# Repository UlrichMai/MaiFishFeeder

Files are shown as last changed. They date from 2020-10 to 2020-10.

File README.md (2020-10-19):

# Smart Fish Feeder

This fish feeder is for a small cylindric aquarium 30x30cm.
The fish need only small amount of food, and most other solution are just to big of unprecise.
This feeder has 14 chambers for food portions.
A 180 degree servo rotates the hole to drop the food.
Once the software is ready, there will be 2 actions that can be controlled
1. feed 1 portion: The disc will rotate to drop the next portion.
2. refill: the disc will rotate to the beginning an you can refill the disc holes.

## Part List
- SG90 servo
- ESP8266 D1 mini
- USB panel jack
- 3D printed parts [top](doc/fishfeeder_top.stl), [body](doc/fishfeeder_body.stl), [bottom](doc/fishfeeder_bottom.stl)

## todo
- improve 3D parts
- decide wether to build my own firmware or to use Tasmota.
  - Tasmota PWM feature is able to control the servo. pwm 38..140 results in the neccessary servo movement
  - the servo its self needs pulses ranging from 750..2600 microseconds for the 180 range
- requirements
  - the current servo position must be persisted
  - a reset or power cycle must not move the servo, so not unwanted food is dropped.

## Whishlist
- add a ESP32 cam as a webcam for the aquarium
- add a water temperatur sensor

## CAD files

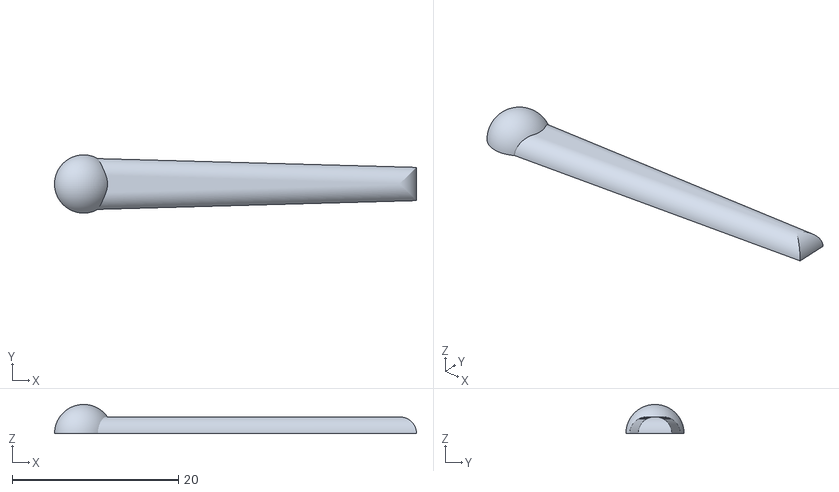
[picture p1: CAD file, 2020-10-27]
doc/Portionierer.stl
43.5 x 7.00 x 3.50

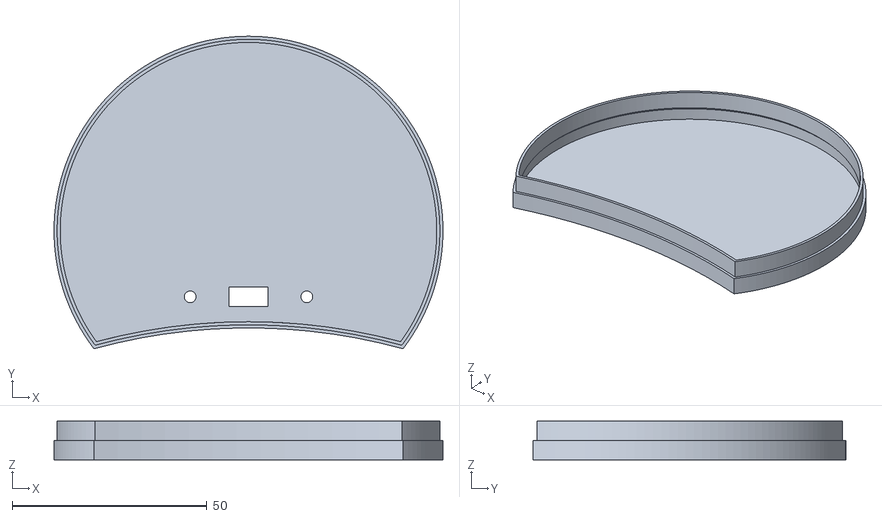
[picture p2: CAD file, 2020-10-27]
doc/fishfeeder_bottom.stl
100.0 x 80.4 x 10.0

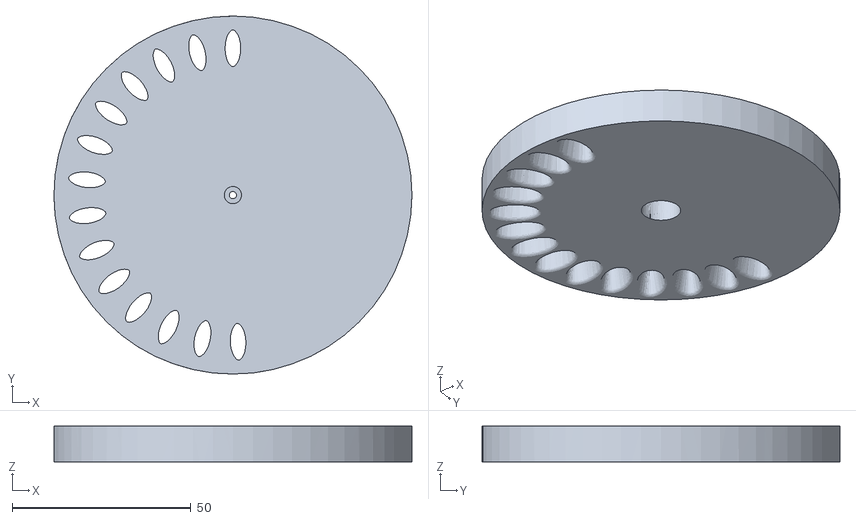
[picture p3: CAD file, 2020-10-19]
doc/fishfeeder_top.stl
100.0 x 100.0 x 9.96

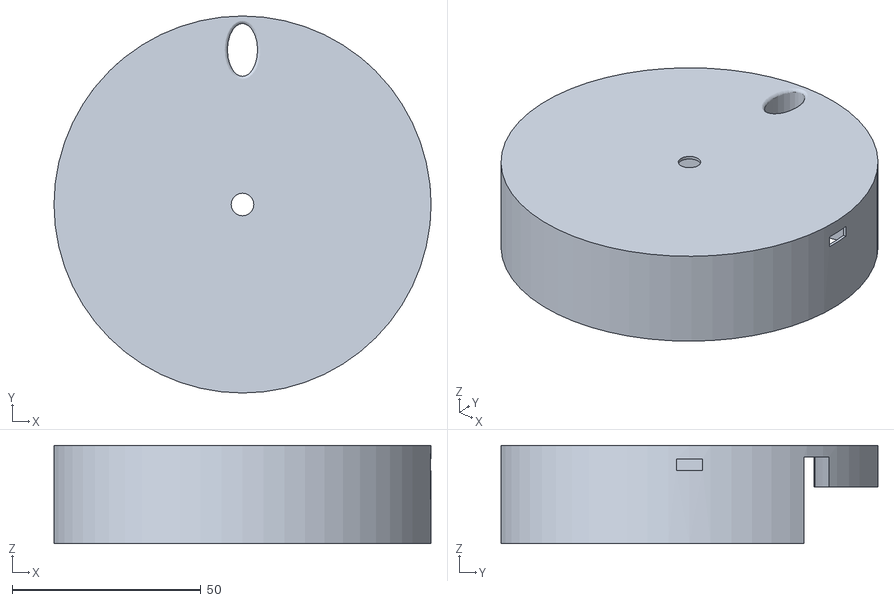
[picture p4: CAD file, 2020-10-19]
doc/fishfeeder_body.stl
100.0 x 100.0 x 26.0

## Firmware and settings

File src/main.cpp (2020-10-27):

#include <Arduino.h>
#include <ESP8266WiFi.h>
#include <ESP8266WebServer.h>
#include <ArduinoOTA.h>
#include <Servo.h>

#include "Private.h"

// Webserver on port 80
ESP8266WebServer server(80);

#define SERVO_PIN 4

Servo myservo;
// cable colors SG90 servo:
// brown=GND, red=5V, orange=pulse 

const int FeederPos[] = {2702,2559,2416,2273,2130,1987,1844,1701,1558,1415,1272,1129,986,843,700,0};
int ServoPos = 0; // to be persisted
uint32_t LastServoMove = 1;

void refill() {
  myservo.attach(SERVO_PIN);
  ServoPos = 0;
  int ms = FeederPos[ServoPos];
  myservo.writeMicroseconds(ms); 
  LastServoMove = millis();
}
void feed() {
  if (FeederPos[ServoPos+1] ==0) {
    return;
  }

  myservo.attach(SERVO_PIN);
  ServoPos++;
  int ms = FeederPos[ServoPos];
  myservo.writeMicroseconds(ms);
  LastServoMove = millis();
}

void setup() {
  Serial.begin(115200);
  Serial.printf("setup...\n");

	WiFi.persistent(false);
	WiFi.mode(WIFI_STA);
	WiFi.setAutoReconnect(true);
	WiFi.begin(ssid, password);
  Serial.printf("wifi...\n");

  ArduinoOTA.setHostname("FishFeeder");
  //ArduinoOTA.setPassword(passwordOTA);
  ArduinoOTA.begin();
  Serial.printf("OTA...\n");

  // Webserver
  server.on("/", []() {
    server.send(200, "text/html", "<html><body> <style>body{font-size:300%;}</style> <h3>Fish Feeder</h3> <p><a href='/feed'>feed</a></p> <p><a href='/refill'>refill</a></p> <p></p></body></html>");
  });
  server.on("/refill", []() {
    refill();
    server.sendHeader("Location", "/",true); 
    server.send(302, "text/plain","ok");  
    server.client().stop();  
  });
  server.on("/feed", []() {
    feed();
    server.sendHeader("Location", "/",true); 
    server.send(302, "text/plain","ok");  
    server.client().stop();  
  });
  server.on("/set", []() {
    if (server.args()>=1) {
      if (server.argName(0).equals("ms")) {
        myservo.writeMicroseconds(server.arg(0).toInt());
      }
    }
    server.sendHeader("Location", "/",true); 
    server.send(302, "text/plain","ok");  
    server.client().stop();  
  });

  server.onNotFound( []() {
    server.send(404, "text/plain", "not found");
  });
  server.begin(); 
  Serial.printf("Webserver...\n");
  
  // Servo
  myservo.attach(SERVO_PIN);
  Serial.printf("servo...\n");
}

void loop() {
  ArduinoOTA.handle();  
  server.handleClient();
  
  //shut off servo after 5s to stop shaking
  if (LastServoMove!=0 && LastServoMove+5000 < millis()) {
    myservo.detach();
    LastServoMove=0;
  }
}

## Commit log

2020-10-17 modified servo lib, no initial movement
2020-10-17 poc: servo positions
2020-10-19 added stl first version
    [fishfeeder_body.stl, fishfeeder_bottom.stl, fishfeeder_top.stl]
2020-10-19 test servo positioning
2020-10-19 botton with more hight and USB cutout
    [fishfeeder_bottom.stl]
2020-10-27 first working version
    [Portionierer.stl, fishfeeder_bottom.stl, pwm values.xlsx]
2020-10-27 shut off servo after 5s to stop shaking
